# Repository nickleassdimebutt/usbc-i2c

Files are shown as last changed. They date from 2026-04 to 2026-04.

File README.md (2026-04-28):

# usbc-i2c

USB-C powered I²C breakout — 5 V in, 3.3 V out, 10 kΩ SDA/SCL pullups,
4-pin header to chain sensors. Power-good LED (green) on +3V3.

PCBA-2 test project for the [kicad-claude-toolkit](https://github.com/nickleassdimebutt/kicad-claude-toolkit)
v3 toolchain. Tighter layout than usbc-charger (14 components vs 23) so
hand-routed tracks could go DRC-clean for the routing that *does* exist.

## Layout status

The validated routes from usbc-3v3 (J1 escape, VBUS bus, CC pulldowns,
GND bridges) are reused verbatim. The new fan-out (+3V3 to LDO output
caps, the I²C pullups, the LED, the 4-pin user header) is left for
KiCad GUI hand-routing — same reason as usbc-charger: code-only routing
without a visual feedback loop accumulates pad-coordinate errors very
quickly.

DRC reports:

- 10 unconnected items — every +3V3 / SDA / SCL / N_D1 stub (expected,
  routing TODO)
- 1 dangling track — leftover endpoint from a stub I trimmed
- 4 cosmetic silk warnings (overlap, edge clearance, copper clip) — all
  non-fatal, would be silenced via project rule overrides

The board is **topologically correct** (`circuit.py` builds, BOM is
clean, schematic SVG renders) and the full datasheet pipeline runs
end-to-end on it.

## Build

```powershell
& "C:\Program Files\KiCad\10.0\bin\python.exe" build.py --datasheet --sim
```

## Topology summary

| Block | Components | Function |
|---|---|---|
| `usbc_power` | J1 + R1, R2 | USB-C 5 V input + CC pulldowns |
| `ldo` | U1 + C1, C2, C3 | AMS1117-3.3 LDO with bypass caps |
| `i2c_pullups` | R10, R11 | 10 kΩ SDA / SCL pullups to +3V3 |
| `led` | D1 + R3 | Green +3V3 power-good indicator |
| `header` | J2 | 4-pin I²C user header (3V3/GND/SDA/SCL) |
| `mounting` | H1, H2 | Two M2 corner holes |

14 components, 8 nets, 50 × 30 mm.

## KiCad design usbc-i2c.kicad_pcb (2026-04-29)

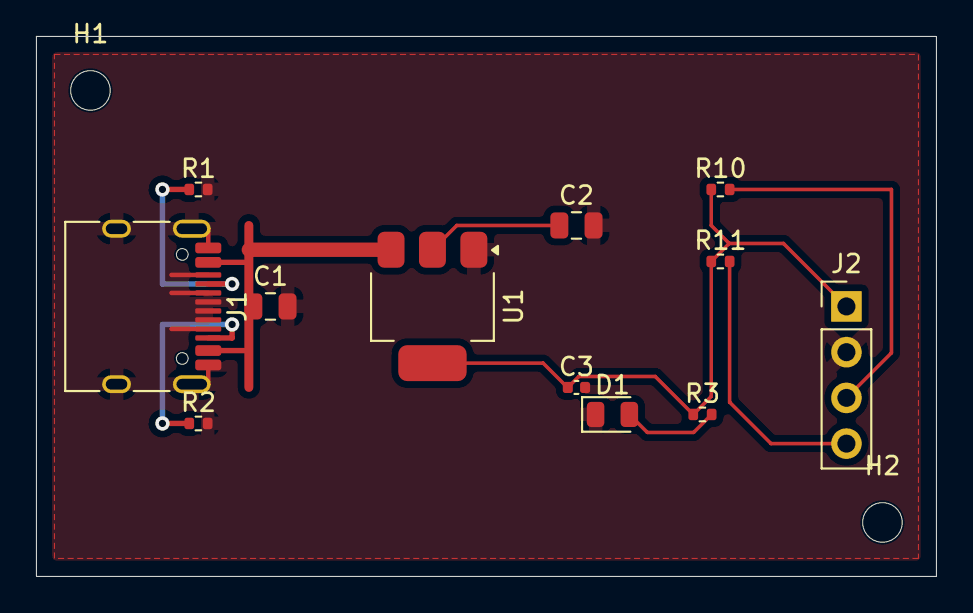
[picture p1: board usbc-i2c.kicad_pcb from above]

Board: 2 copper layers, 50.0 x 30.0 mm, 14 parts (0 on the bottom side), 8 nets.

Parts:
C1, C2: 10uF; C_0805_2012Metric
C3: 100nF; C_0402_1005Metric
D1: GREEN; LED_0805_2012Metric
H1, H2: MountingHole_M2; MountingHole_2.2mm_M2
J1: HRO TYPE-C-31-M-12; USB_C_Receptacle_HRO_TYPE-C-31-M-12
J2: I2C; PinHeader_1x04_P2.54mm_Vertical
R1, R2: 5.1k; R_0402_1005Metric
R3: 820.0; R_0402_1005Metric
R10, R11: 10k; R_0402_1005Metric
U1: AMS1117-3.3; SOT-223-3_TabPin2

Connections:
+3V3: C2.1, C3.1, J2.1, R3.1, R10.1, R11.1, U1.2
CC1: J1.A5, R1.1
CC2: J1.B5, R2.1
GND: C1.2, C2.2, C3.2, D1.1, J1.A1, J1.A6, J1.A7, J1.A8, J1.A12, J1.B1, J1.B6, J1.B7, J1.B8, J1.B12, J1.SH, J2.2, R1.2, R2.2, U1.1
N_D1: D1.2, R3.2
SCL: J2.4, R11.2
SDA: J2.3, R10.2
VBUS: C1.1, J1.A4, J1.A9, J1.B4, J1.B9, U1.3

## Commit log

2026-04-28 feat: usbc-i2c PCBA-2 — USB-C-powered I²C breakout
    14-component board: USB-C → AMS1117-3.3 → 4-pin I²C header (3V3/GND/
    SDA/SCL) with 10 kΩ pullups and a green power-good LED. Six blocks
    (usbc_power, ldo, i2c_pullups via inline Component+block_scope, led,
    header, mounting) — exercises the toolkit on a slightly different
    topology than usbc-3v3 / usbc-charger.
    Layout reuses usbc-3v3's validated USB-C escape, VBUS bus, CC pulldown
    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
    [usbc-i2c.kicad_pcb]
2026-04-29 chore(layout): extract_layout round-trip — captures hand-routed I²C fan-out
    User routed +3V3 / SDA / SCL / N_D1 in KiCad GUI; extract_layout pulled
    the resulting 44 tracks (was 20) into layout.py via the four-marker-block
    format. 9 of 10 unconnected items resolved.
    Round-trip note: rebuilding from layout.py produces 7 violations + 3
    unconnected, vs the saved KiCad PCB at 29 + 1. The delta:
    - zone clearance violations vanish on rebuild because build_pcb
    creates but doesn't auto-fill zones (KiCad fills on edit, so the
    saved PCB shows real-copper clearance checks)
    - 2 connections KiCad auto-snapped (track endpoints near but not
    exactly on pads) get lost — the round-trip ca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
    [usbc-i2c.kicad_pcb]
